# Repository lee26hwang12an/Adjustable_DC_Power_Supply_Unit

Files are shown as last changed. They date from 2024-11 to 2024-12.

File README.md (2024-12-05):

# ADJUSTABLE DC POWER SUPPLY UNIT
*My special thanks to my friend, my colleague, Trần Ngọc Duy (Lý Hoàng Duy), without whose support I couldn't have managed this project. I would also like to express my gratitude towards my colleague, my master, [Mr. Nghĩa](https://github.com/nghiank97) at Apicoo Robotics for his unparalleled knowledge of various communication systems. Thank you all for your contribution and dedication.*

***IN PROGRESS***

#
## ABOUT
<div align="justify">
As an electronics and prototyping hobbyist, the need for a power supply unit of a wide range of voltages and amperes yields that either I purchased a pre-built DC power supply, or hook up some buck-boost circuitries to a fixed one. Through market research and online shopping malls surveys, I came to the realization that pre-built DC PSUs are either too expensive or have very limited range of output. Hooking up a buck-boost converter to a fixed voltage PSU is a primitive idea yet surprisingly efficient in terms of price/performance. However, the hassle of having to get finicky with a screw driver and multimeter when manually adjusting the converter is loosely a deal breaker for this idea.

######
So I headed out to one of my friends, Trần Ngọc Duy, and was suggested a buck converter with adjusting knobs and LCD screen that could display current and set parameters. The buck converter <b><i>XY-6014</i></b> was designed for CNC machinery applications, but could be fitted to serve virtually any systems. And that was what I went for.
######
Then came the part of designing a case that provides housing for the components. The PSU is made up of a 36V DC unit, the buck converter mentioned above, an AC power inlet, a microcontroller that can read serial data from the buck converter, and write certain effects to an LED strip that I mounted underneath the PSU, mainly for aesthetic purposes.
</div>

<div align="center">Darstellar PSU</div>

#
## COMPONENTS
- x1 36V-10A AC-DC Power Supply Unit
- x1 XY-6014 Buck Converter
- x1 5V Regulator
- x1 STM32F103C6T6A MCU
- x17 WS2812B RGB LED
- x2 (Manufactured) 310mm x 210mm x 3mm Aluminum Plates
- x1 (Manufactured) 310mm x 210mm x 3mm Black Acrylic Panel
- x3 (Manufactured) PETG Housing Parts
- x1 AC Inlet with Switch
- x1 AC Cable

#
## MECHANICAL DESIGN
<div align="justify">
The case parts for the PSU were designed in Solidworks. Initially I aimed to 3D print them all entirely, with hope that certain geometrically creative designs could be implemented. I took some references online on Pinterest and Google, looking for innovative concepts, and have stumbled upon various designs by incredible people.
</div>

######
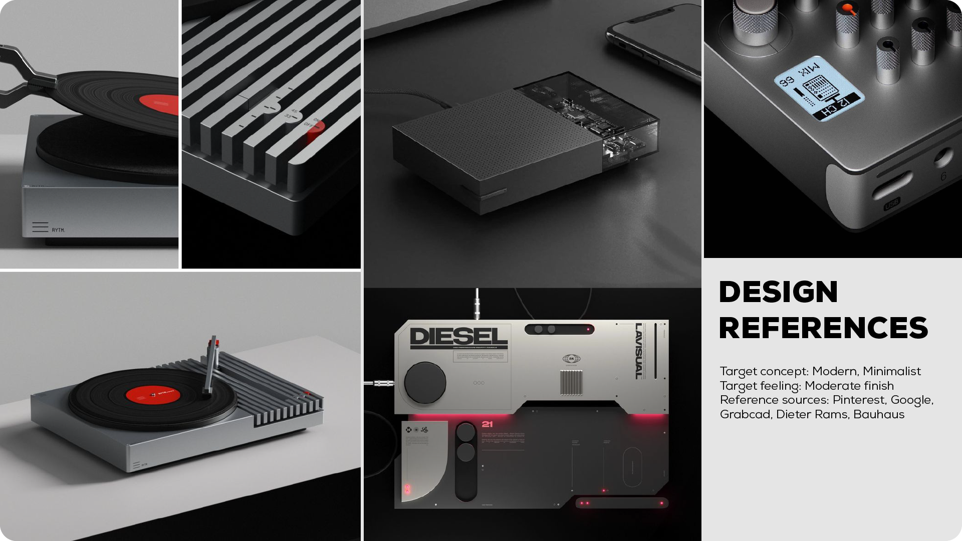
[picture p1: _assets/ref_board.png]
Design References


######
<div align="justify">
But then I asked myself the question: Do I want it to look good? Or do I want it to also feel good to the touch? And not to mention the aspect of ergonomic and friendly design. Now with reprap (3D printing), I could have manufactured virtually any shapes and forms, but it wouldn't be able to rival the quality by CNC machining, and touching plastic would feel somewhat cheaper than touching, say, aluminum or glass. So after some considerations, I decided that my prototype must have non-industrial design, meaning that it must look like it belongs to a consumer's house, on a desk, not in a factory, and the corners should be rounded (I hate sharp corners). Furthermore, it should have certain parts where touching gives a sense of high quality and finish. In the end, I arrived at the design shown below:
</div>

######
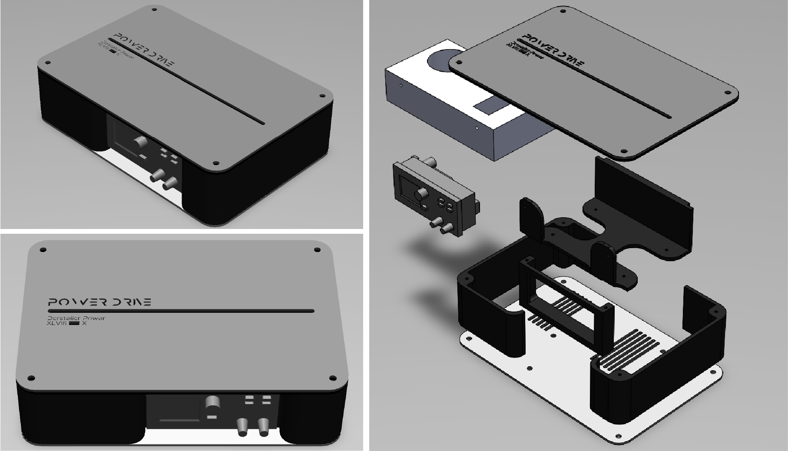
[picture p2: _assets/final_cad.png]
Final Design


######
<div align="justify">
For manufacturing, every parts with complex form such as the side walls, the buck and AC-DC mounts were 3D printed using PETG filament. I especially increased the infill density to around 25% to achieve a tougher result. The top and bottom panels were of aluminum material, and were made by ordering local laser cutting shops in my region.
</div>

######
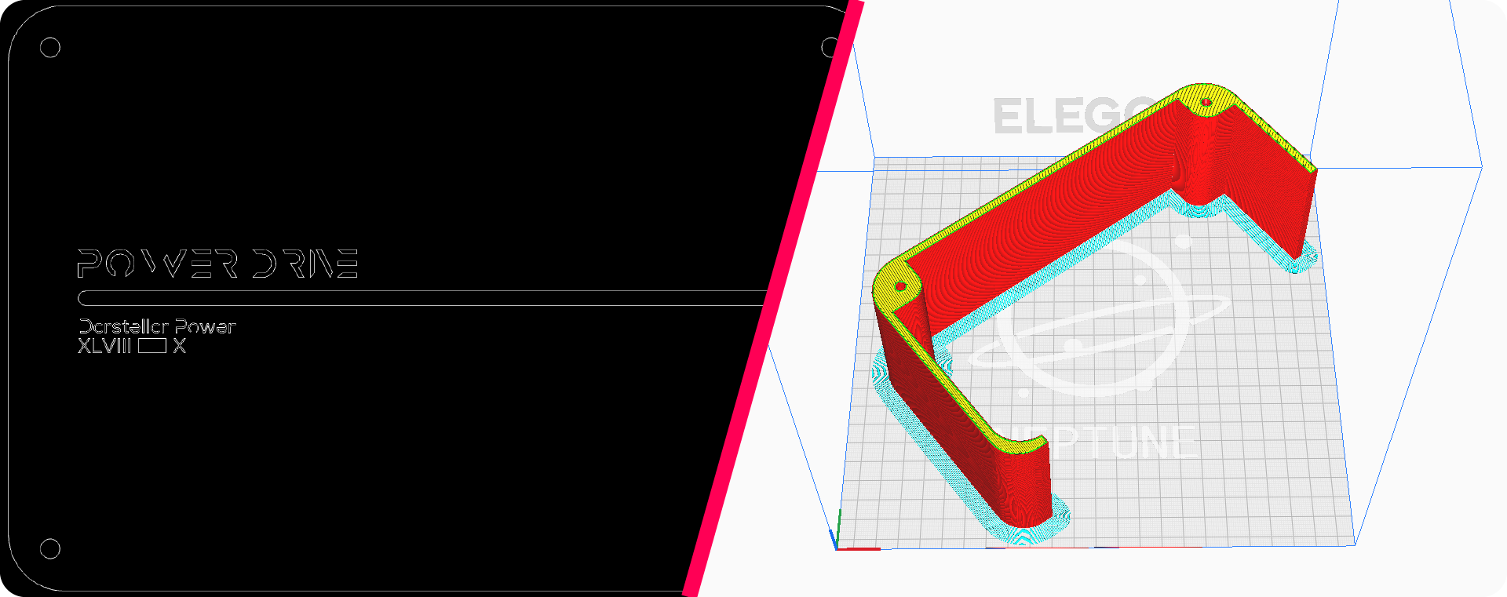
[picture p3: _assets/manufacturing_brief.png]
Manufacture Files


#####
And finally, the prototype: (Please excuse the cables, it was still in development the moment I took the pictures)

######
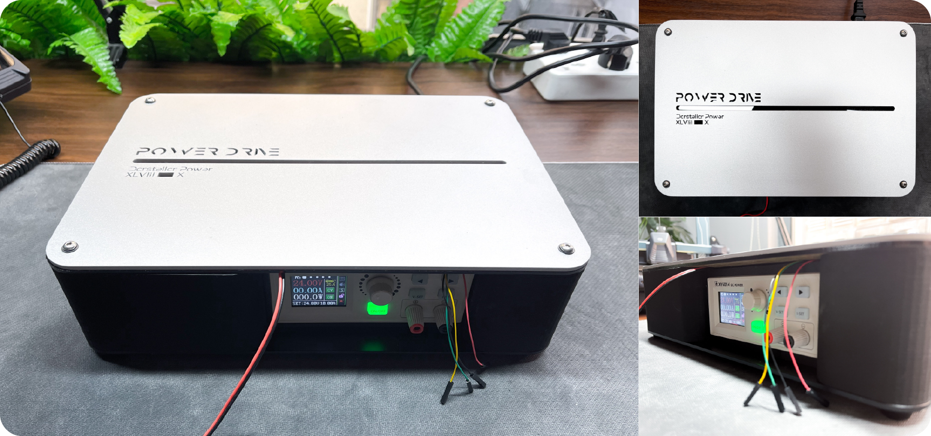
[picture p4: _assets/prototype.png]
Final Product


#
## MODBUSRTU AND WS2812B FIRMWARE
<div align="justify">
Okay, I know what you're thinking, what does Modbus RTU have to do with this amature PSU, and why even bother adding LEDs? Well, first, I like LEDs and making colors. Second, I like to make consumers-targetted products, so appearance definitely matters. Third, screw you all who say Functionalities over Aesthetics. Aesthetics is the key force that drives functionalities forward. Think of a Ford car at the very beginning of the automobile age, then think of any modern day cars: If they didn't want to imporve on the aesthetic aspect, why would you need complex CAN and LIN buses inside a thing made purely for traveling and not for entertaining or showing off purposes? I'm not saying Aesthetics over Functionalities, but in general they should be put side by side. To me, a good design has to base its functionalities around aesthetics, and the chosen aesthetics must revolve around its predetermined functionalities. Now back to fourth, the XY-6014 buck actually has a wifi module that could communicate with the base circuit through Serial using Modbus RTU. I did not, however, get the wifi version, so I have the Serial port hanging there for free doing nothing. And if it's there and I paid for it, it would be a sin not to utilize the product to its fullest.
</div>

##
### WS2812B with STM32 Timer and DMA
<div align="justify">
Why didn't I just use already existing libraries for driving these LEDs, such as FastLED or something like that? Well 3 reasons: Number 1, I don't know how to port those to the STM32 platform, number 2, those libraries don't have the functions and effects that I need, and number 3, those libraries have the functions and effects that I do not need. So I thought I would write my own program, with my own effects and functions.
</div>

######
<div align="justify">
I will not go into details on how to actually setup and configure STM32 peripherals and DMA to write data to the LEDs here since there have been countless tutorials online. I will, however, leave a link here to another repository of mine that is dedicated to solely driving WS2812B LEDs with STM32 Timer and DMA. If the link is not available, come back later, I didn't have the time to write a complete README yet.
</div>

######
Regarding ModbusRTU, it's the same. It is actually quite easy in terms of programming, since making a ModbusRTU client to send and read data on holding registers is rather simple, compared to writing a program for an RTU server.

######
So basically this is the flowchart for my STM32 ModbusRTU client + LEDs driver:
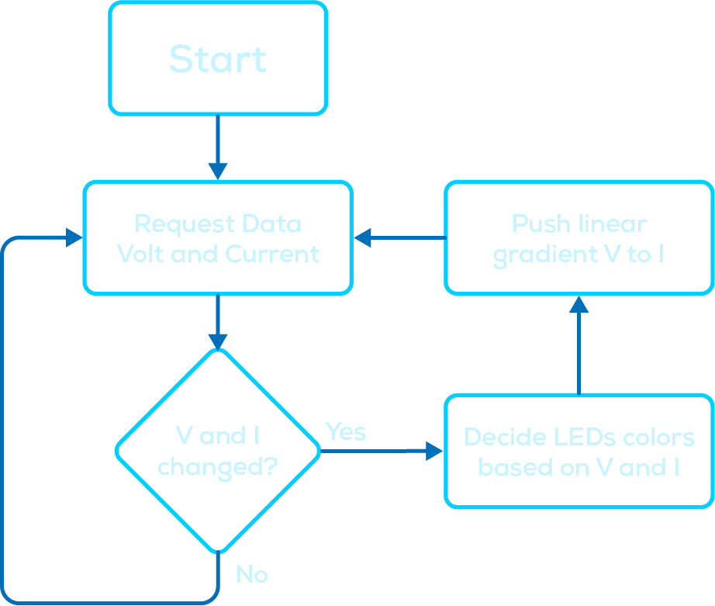
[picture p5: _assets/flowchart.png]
Flowchart


######
The STM32 client requests data from the XY-6014 server every 2 seconds by calling:
```cpp
modbusClient.request(XY_6014_SERVER_ADDRESS, MODBUS_RTU_READ_HOLDING_REGISTERS, START_ADDRESS, DATA_BYTES_COUNT);
```
Then by switching the received values for Voltage and Current, the colors for the LEDs are decided. This scheme is arbitrary, but I'm choosing: Blue for 0-5V 0-1A, Cyan for 5-10V 1-3A, Green for 10-15V 3-5A, Yellow for 15-20V 5-7A, Orange for 20-25V 7-10A, Red for 25-30V 10A-12A, Purple for 30V+ 12A+.
```cpp
led.gradient2Colors(voltColor, startLED, ampColor, endLED);
led.transition(HAL_GetTick(), TRANSITION_DURATION_MS);
```
And the result:
(To be updated)

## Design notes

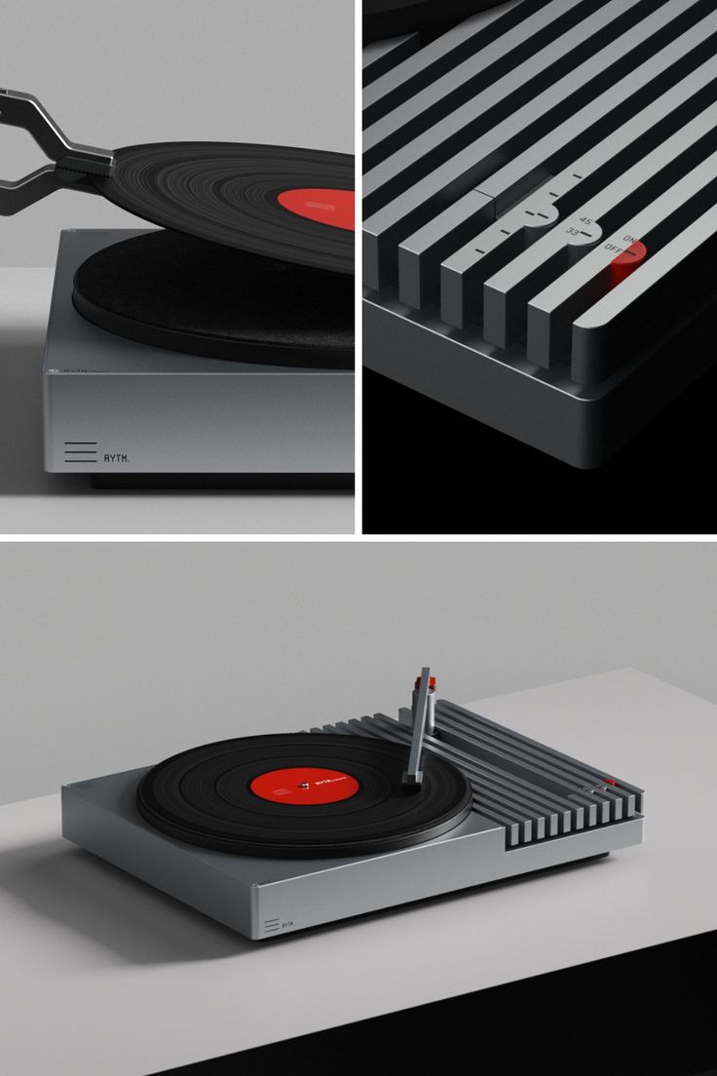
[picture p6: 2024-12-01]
_assets/ref_1.jpg

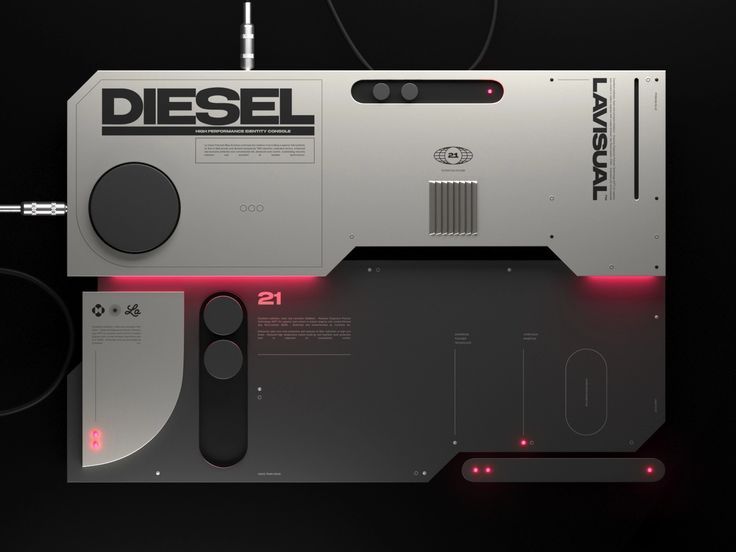
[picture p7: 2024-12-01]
_assets/ref_3.jpg

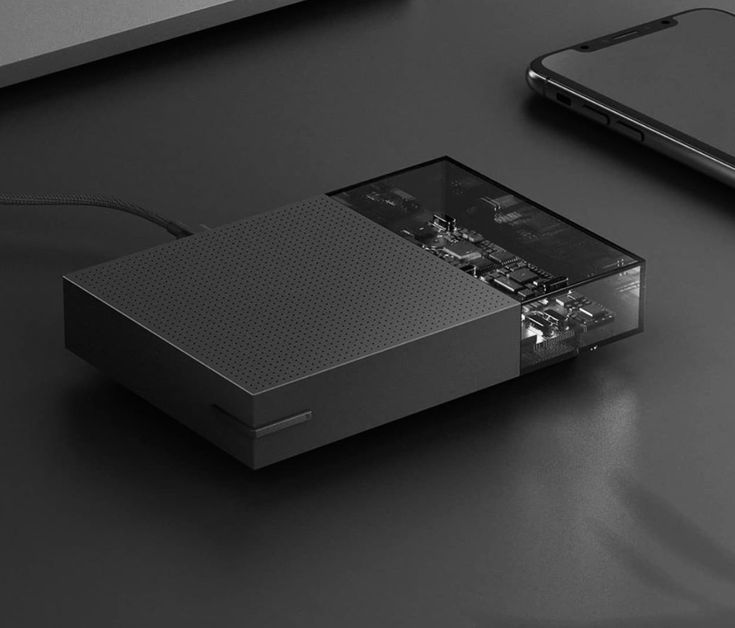
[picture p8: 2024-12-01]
_assets/ref_2.jpg

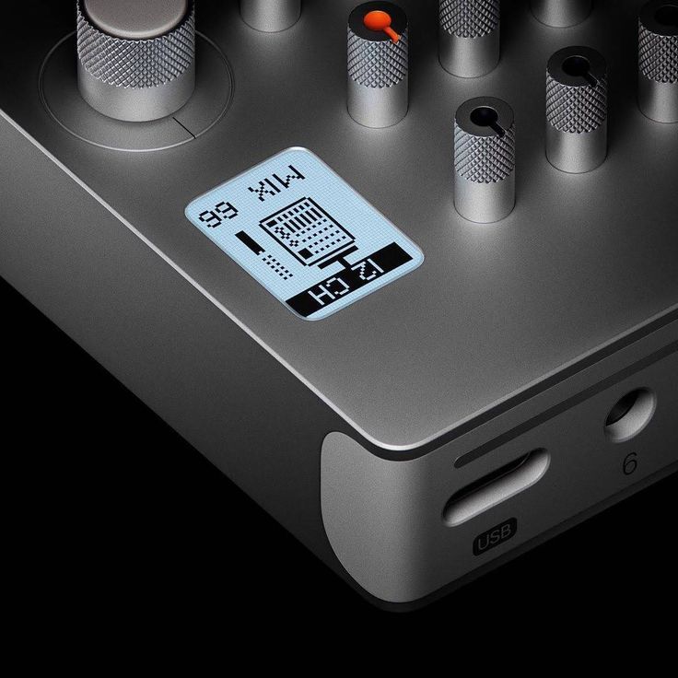
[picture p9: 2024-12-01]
_assets/ref_4.jpg

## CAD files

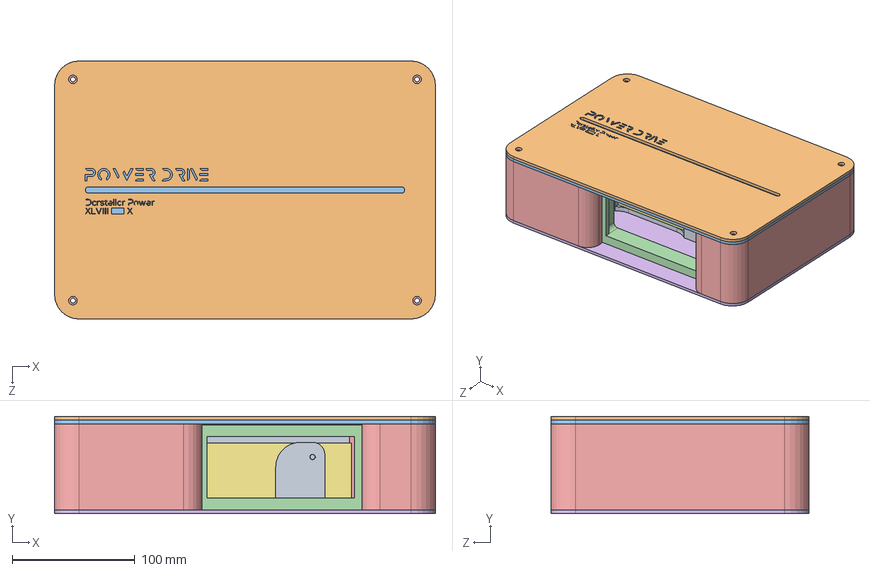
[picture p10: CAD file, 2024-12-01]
_mechanical/model_1.SLDASM
310.0 x 79.0 x 210.0 mm
bot_alu_3
wall_1
wall_2
48v10a_template
top_mica_black
top_alu_3
power_holder

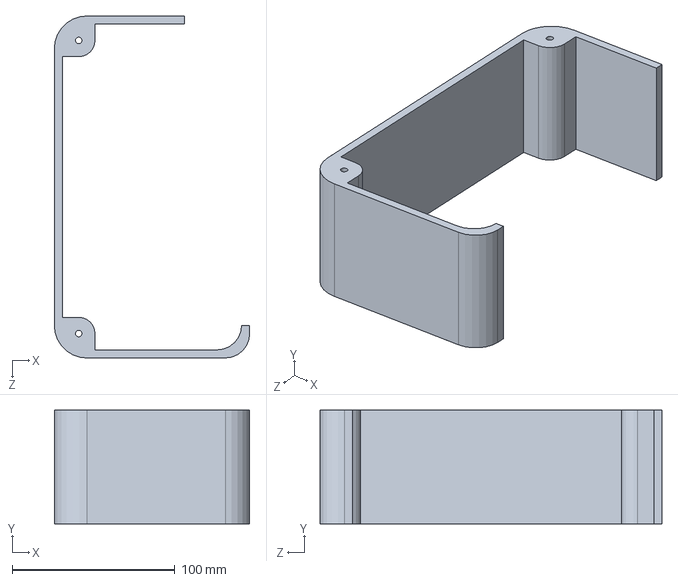
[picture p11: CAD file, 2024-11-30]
_mechanical/[PRINT]_wall_1a.SLDPRT
120.0 x 70.0 x 210.0 mm

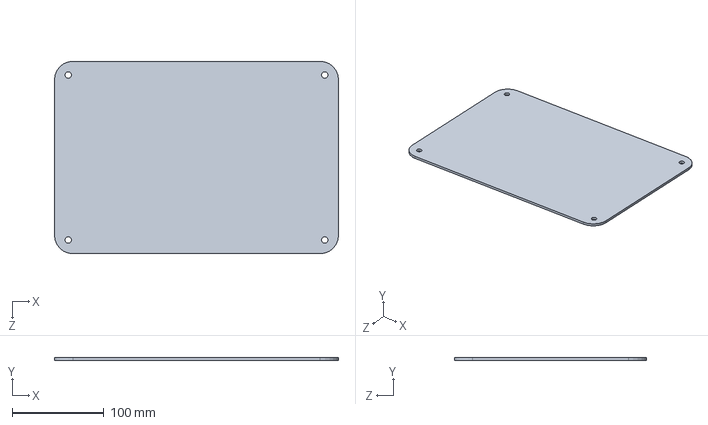
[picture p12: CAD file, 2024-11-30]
_mechanical/top_mica_black.SLDPRT
310.0 x 3.00 x 210.0 mm

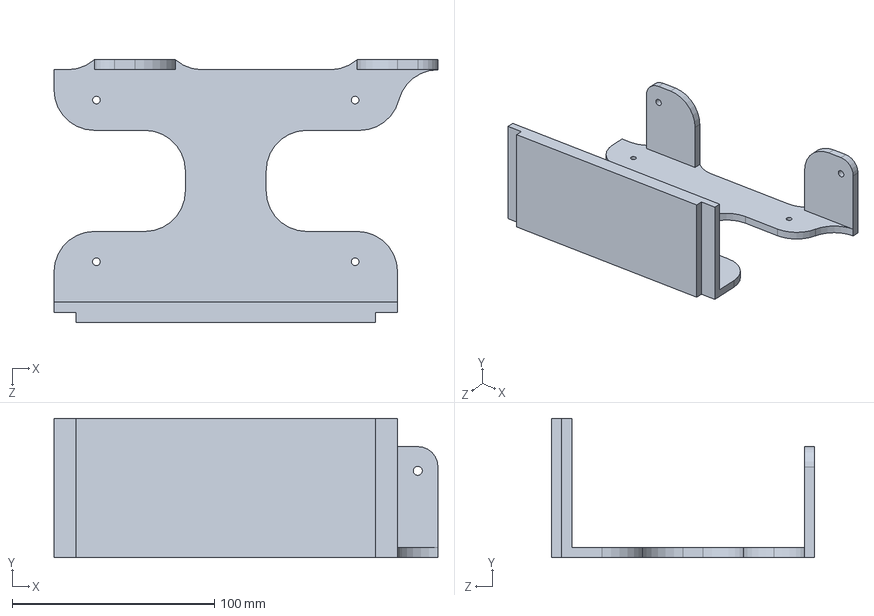
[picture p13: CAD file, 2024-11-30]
_mechanical/[PRINT]_power_holder.SLDPRT
190.0 x 69.0 x 130.0 mm

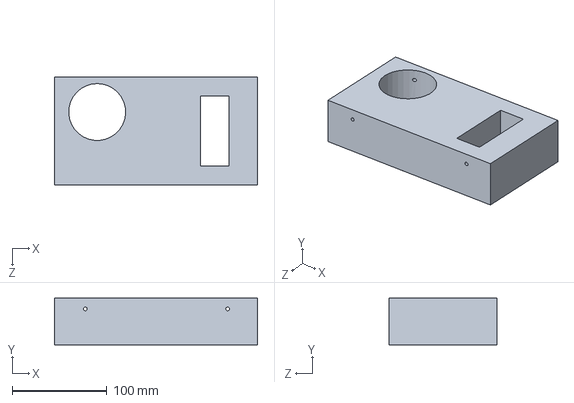
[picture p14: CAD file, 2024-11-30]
_mechanical/48v10a_template.SLDPRT
214.0 x 49.5 x 114.0 mm

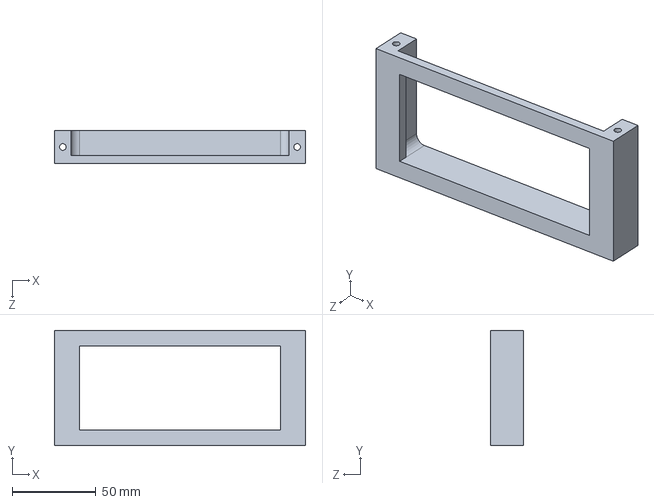
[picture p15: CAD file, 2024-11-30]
_mechanical/wall_2.SLDPRT
150.0 x 69.0 x 20.0 mm

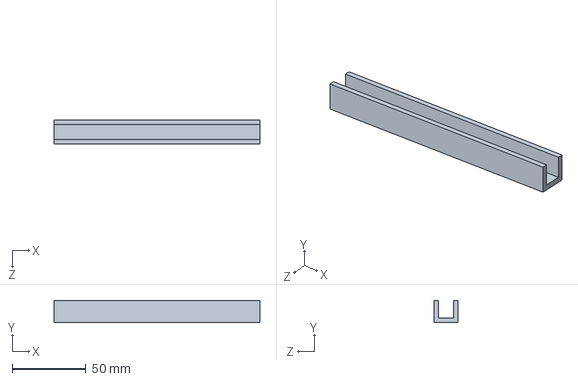
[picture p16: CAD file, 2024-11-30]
_mechanical/led_holder.SLDPRT
140.0 x 15.0 x 16.0 mm

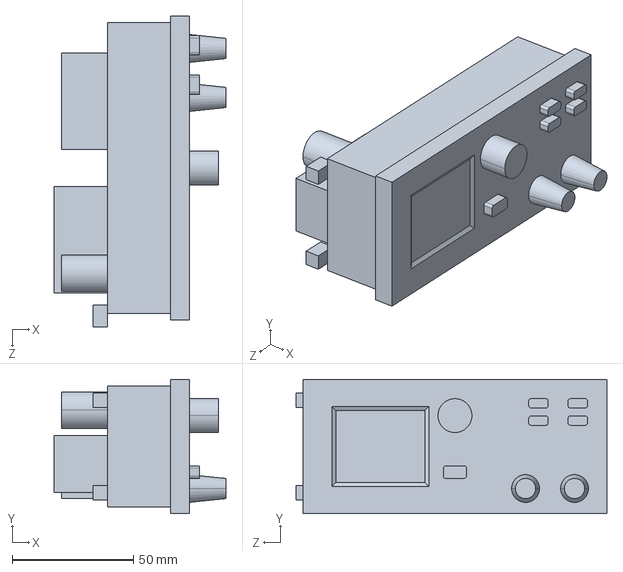
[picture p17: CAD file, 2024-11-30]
_mechanical/XY6014.STEP
71.0 x 55.5 x 128.3 mm

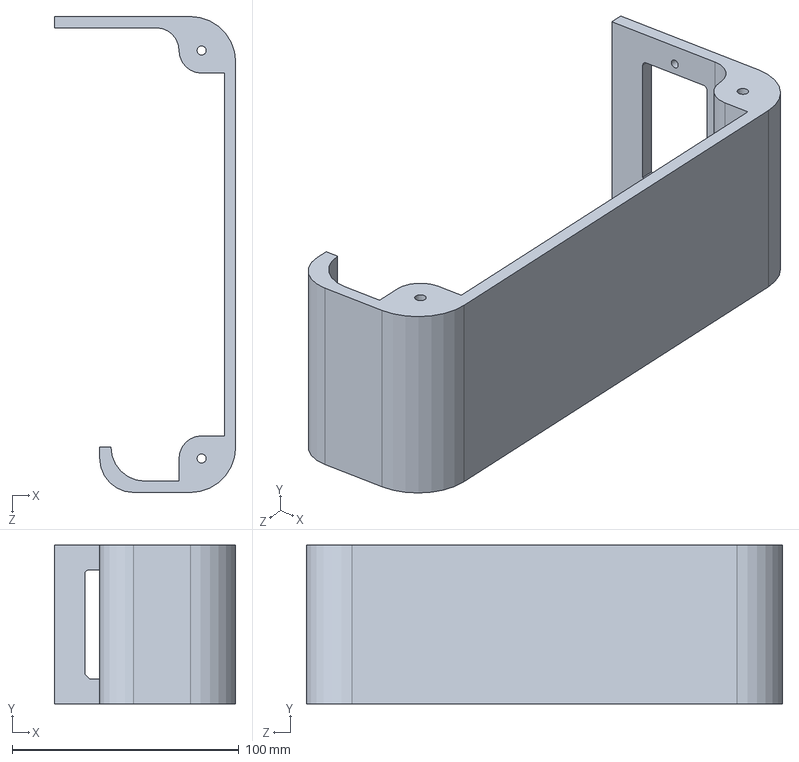
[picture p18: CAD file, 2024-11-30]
_mechanical/[PRINT]_wall_1b.SLDPRT
80.0 x 70.0 x 210.0 mm

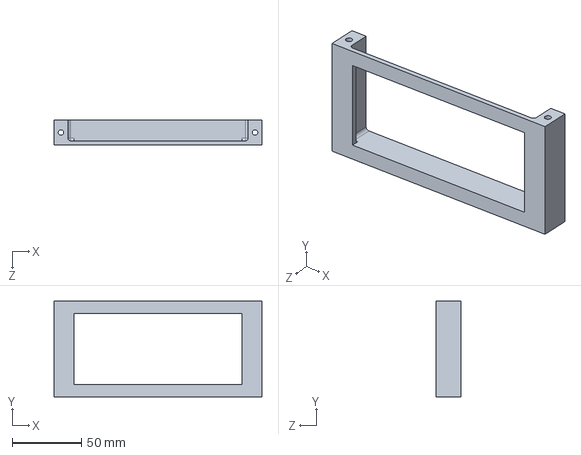
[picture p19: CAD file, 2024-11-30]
_mechanical/[PRINT]_wall_2.SLDPRT
150.0 x 69.0 x 18.0 mm

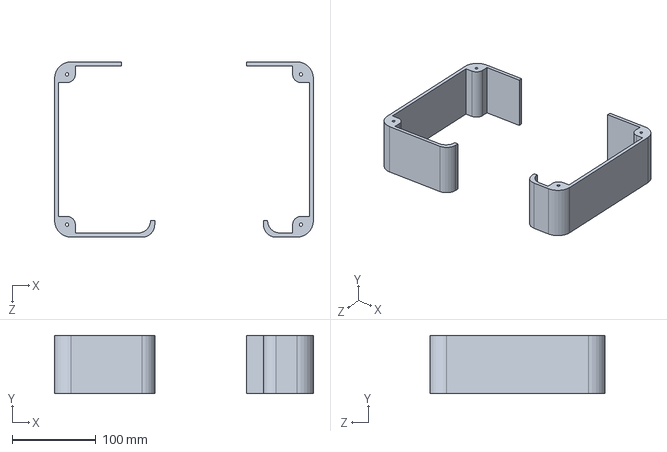
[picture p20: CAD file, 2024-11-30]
_mechanical/wall_1.SLDPRT
310.0 x 70.0 x 210.0 mm

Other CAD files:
_mechanical/top_alu_3.SLDPRT
_mechanical/power_holder.SLDPRT
_mechanical/[LASER]_top_alu_3.DWG
_mechanical/bot_alu_3.SLDPRT
_mechanical/[LASER]_bot_alu_3.DWG
_mechanical/[LASER]_top_mica_black.DWG
_mechanical/[PRINT]_power_holder.STL
_mechanical/[PRINT]_wall_1a.STL
_mechanical/[PRINT]_wall_1b.STL
_mechanical/[PRINT]_wall_2.STL

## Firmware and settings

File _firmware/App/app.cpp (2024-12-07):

#include "app.h"
#include "stm32Abstract.h"
#include "ws2812b.h"
#include "modbusRTU.h"
#include <stdio.h>


/*
=====================================================================
    MISCELLANEOUS
=====================================================================
*/
extern UART_HandleTypeDef huart2;
#ifdef __cplusplus
extern "C" {
#endif /* __cplusplus */
#ifdef __GNUC__
#define PUTCHAR_PROTOTYPE int __io_putchar(int ch)
#else
#define PUTCHAR_PROTOTYPE int fputc(int ch, FILE *f)
#endif
PUTCHAR_PROTOTYPE
{
    // -------------- Change huart_x to your appropriate Hardware UART/USART
    HAL_UART_Transmit(&huart2, (uint8_t *)&ch, 1, HAL_MAX_DELAY);
    return ch;
}
#ifdef __cplusplus
}
#endif /* __cplusplus */

#define __BLUE      0x001FFF
#define __CYAN      0x22FFEE
#define __GREEN     0x00FF00
#define __YELLOW    0xFFAA00
#define __ORANGE    0xFF3300
#define __RED       0xFF0000
#define __PURPLE    0x6900FF


/*
=====================================================================
    INSTANCING
=====================================================================
*/

#define __LEDS_COUNT 16
extern TIM_HandleTypeDef htim1;
extern DMA_HandleTypeDef hdma_tim1_ch1;
WS2812B led = WS2812B(&htim1, TIM_CHANNEL_1, __LEDS_COUNT);

#define __SLAVE_ADDRESS     0x01
#define __ON_OFF_REG        0x0012
#define __VOLT_AMP_REG      0x0002
extern UART_HandleTypeDef huart1;
ModbusRTU modbusClient = ModbusRTU(&huart1);

extern TIM_HandleTypeDef htim2; // 1kHz timer to get miliseconds
#define __START_TICK_COUNTING() HAL_TIM_Base_Start_IT(&htim2)
float tick = 0.00f;

uint8_t valueChanged = 0;
uint8_t volt_MSB, volt_LSB, curr_MSB, curr_LSB;


/*
=====================================================================
    SETUP
=====================================================================
*/
void setup()
{
    HAL_Delay(1000);

    // --------------------------------------------------------- INIT
    led.init();
    modbusClient.init();

    // ------------------------------------------ LED START-UP EFFECT
    led.solidColor(0x000000, 0, __LEDS_COUNT - 1);
    led.render();
    HAL_Delay(500);
    for (uint8_t blinks = 0; blinks < 5; blinks++)
    {
        led.solidColor(0xFF0000, 0, __LEDS_COUNT / 2 - 1);
        led.solidColor(0x000000, __LEDS_COUNT / 2, __LEDS_COUNT);
        led.render();
        HAL_Delay(200);
        led.solidColor(0x000000, 0, __LEDS_COUNT / 2 - 1);
        led.solidColor(0x0000FF, __LEDS_COUNT / 2, __LEDS_COUNT);
        led.render();
        HAL_Delay(200);
    }
    led.solidColor(0x000000, 0, __LEDS_COUNT - 1);
    led.render();
    HAL_Delay(500);

    // --------------------------------------- START TIMERS CALLBACKS
    __START_TICK_COUNTING();
    led.startCallbackClock();
}


/*
=====================================================================
    MAIN LOOP
=====================================================================
*/
void loop()
{
    if (!valueChanged)
        return;

    led.stopCallbackClock();

    if (modbusClient.receiveBuffer[3] != volt_MSB ||
        modbusClient.receiveBuffer[4] != volt_LSB ||
        modbusClient.receiveBuffer[5] != curr_MSB ||
        modbusClient.receiveBuffer[6] != curr_LSB)
    {
        volt_MSB = modbusClient.receiveBuffer[3];
        volt_LSB = modbusClient.receiveBuffer[4];
        curr_MSB = modbusClient.receiveBuffer[5];
        curr_LSB = modbusClient.receiveBuffer[6];
    }
    else
    {
        led.startCallbackClock();
        return;
    }

    uint16_t volt = ((uint16_t)volt_MSB << 8) | ((uint16_t)volt_LSB << 0);
    uint16_t curr = ((uint16_t)curr_MSB << 8) | ((uint16_t)curr_LSB << 0);
    uint32_t ledVolt, ledAmps;

    if (volt <= 5 && curr <= 3)
    {
        modbusClient.request(
            __SLAVE_ADDRESS, MODBUS_RTU_READ_HOLDING_REGISTERS,
            __ON_OFF_REG, 1
        );
        uint8_t state = modbusClient.receiveBuffer[4];
        if (state == 0)
        {
            ledVolt = 0;
            ledAmps = 0;
            modbusClient.request(
                __SLAVE_ADDRESS, MODBUS_RTU_READ_HOLDING_REGISTERS,
                __VOLT_AMP_REG, 0x02);
            goto BUTTON_OFF;
        }
    }

    if (__inProximity(volt, 250, 250))
        ledVolt = __BLUE;
    else if (__inProximity(volt, 750, 250))
        ledVolt = __CYAN;
    else if (__inProximity(volt, 1250, 250))
        ledVolt = __GREEN;
    else if (__inProximity(volt, 1750, 250))
        ledVolt = __YELLOW;
    else if (__inProximity(volt, 2250, 250))
        ledVolt = __ORANGE;
    else if (__inProximity(volt, 2750, 250))
        ledVolt = __RED;
    else if (volt > 3000)
        ledVolt = __PURPLE;
    
    if (__inProximity(curr, 50, 50))
        ledAmps = __BLUE;
    else if (__inProximity(curr, 200, 100))
        ledAmps = __CYAN;
    else if (__inProximity(curr, 400, 100))
        ledAmps = __GREEN;
    else if (__inProximity(curr, 600, 100))
        ledAmps = __YELLOW;
    else if (__inProximity(curr, 800, 100))
        ledAmps = __ORANGE;
    else if (__inProximity(curr, 950, 50))
        ledAmps = __RED;
    else if (curr > 1000)
        ledAmps = __PURPLE;

    BUTTON_OFF:
    printf("%.2f\t%.2f\n", (float)volt / 100.0f, (float)curr / 100.0f);
    led.gradient2Colors(ledVolt, 0, ledAmps, __LEDS_COUNT - 1);
    tick = 0;
    while (led.transition(&tick, 1000) != WS2812B_TRANSITION_FINISHED);

    valueChanged = 0;
    led.startCallbackClock();
}


/*
=====================================================================
    CALLBACKS
=====================================================================
*/
void HAL_TIM_PWM_PulseFinishedCallback(TIM_HandleTypeDef *htim)
{
    HAL_TIM_PWM_Stop_DMA(&htim1, TIM_CHANNEL_1);
    led.UPDATE_STATE = WS2812B_UPDATE_FINISHED;
}

#define CALLED_TIMES_UNTIL_TRIGGERED (3125 * 2) // 2-second callback
uint16_t callbackCounter = 0;
void HAL_TIM_PeriodElapsedCallback(TIM_HandleTypeDef *htim)
{
    if (htim->Instance == TIM1)
    {
        callbackCounter++;
        if (callbackCounter < CALLED_TIMES_UNTIL_TRIGGERED)
            return;

        modbusClient.request(
            __SLAVE_ADDRESS, MODBUS_RTU_READ_HOLDING_REGISTERS,
            __VOLT_AMP_REG, 0x02);
        valueChanged = 1;
        callbackCounter = 0;

        __STM32flipGPIO(PC13);
    }
    if (htim->Instance == TIM2)
    {
        tick++;
    }
}

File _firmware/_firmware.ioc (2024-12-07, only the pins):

Mcu.UserName=STM32F103C8Tx
PA10.Signal=USART1_RX
PA13.Signal=SYS_JTMS-SWDIO
PA14.Signal=SYS_JTCK-SWCLK
PA2.Signal=USART2_TX
PA3.Signal=USART2_RX
PA8.GPIO_Label=LED_SIGNAL
PA8.Signal=S_TIM1_CH1
PA9.Signal=USART1_TX
PC13-TAMPER-RTC.GPIO_Label=LED_DEBUG
PC13-TAMPER-RTC.Signal=GPIO_Output
PD0-OSC_IN.Signal=RCC_OSC_IN
PD1-OSC_OUT.Signal=RCC_OSC_OUT

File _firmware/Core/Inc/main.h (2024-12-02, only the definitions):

#define LED_DEBUG_Pin GPIO_PIN_13
#define LED_DEBUG_GPIO_Port GPIOC
#define LED_SIGNAL_Pin GPIO_PIN_8
#define LED_SIGNAL_GPIO_Port GPIOA

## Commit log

2024-11-30 All Files
    [48v10a_template.SLDPRT, XY6014.STEP, [LASER]_bot_alu_3.DWG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]
2024-11-30 Added comments for LED class methods
2024-12-01 Added functions for STM32Abstract

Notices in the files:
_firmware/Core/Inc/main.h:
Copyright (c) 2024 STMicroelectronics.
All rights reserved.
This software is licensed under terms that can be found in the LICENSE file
